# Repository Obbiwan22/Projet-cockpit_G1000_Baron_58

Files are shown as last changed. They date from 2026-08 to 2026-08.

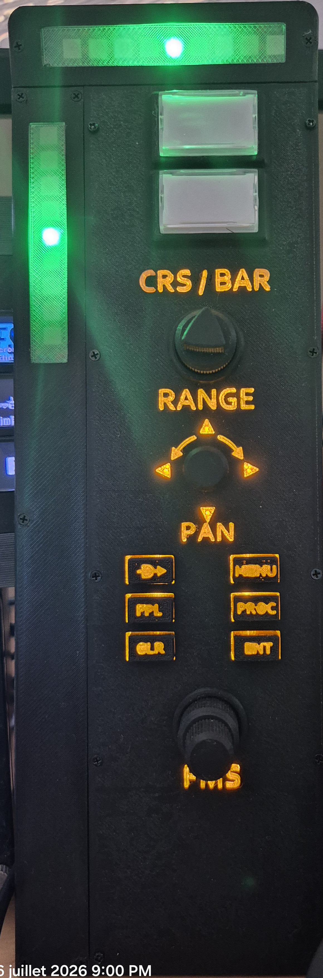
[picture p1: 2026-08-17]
img/G1000.jpg

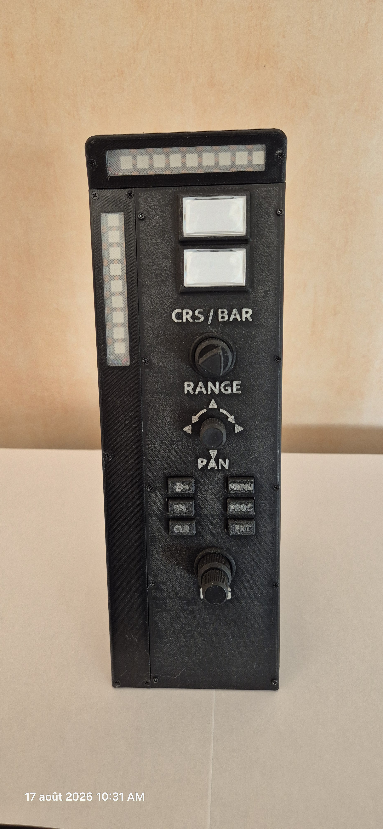
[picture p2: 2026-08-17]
img/Face.jpg

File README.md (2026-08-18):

# G1000 Baron 58 — Cockpit Panel (COMMANDE G1000)

Panneau de commande physique pour le G1000 du Beechcraft Baron 58 sous Microsoft Flight Simulator 2024/2020, piloté par un Arduino Mega 2560 Pro Mini via MobiFlight.





## En bref

Adepte de Flight Simulator, je voulais accéder facilement aux commandes du G1000 sans construire un home cockpit complet. Ce dépôt contient tout ce qu'il faut pour reproduire un panneau de commande physique complet : encodeurs CRS/BARO et FMS, joystick 4 axes, boutons G1000, Master Alarm/Caution avec voyants et alarme sonore, rétro-éclairage variable, et une barre LED qui reproduit l'indicateur de déviation ILS (Localizer/Glideslope).

Le morceau qui a demandé le plus de travail — la barre ILS — a nécessité plusieurs refontes du firmware avant d'obtenir un comportement fiable en vol. Le détail complet de cette investigation est dans le rapport technique (voir plus bas), pour ceux que ça intéresse.

## Démonstration vidéo

- 🎥 [Démonstration 1](https://www.youtube.com/watch?v=X_OnPQQrdoY)
- 🎥 [Démonstration 2](https://www.youtube.com/watch?v=7gS3sEIO30M)

## Ce que contient la carte

| Fonction | Détail |
|---|---|
| Microcontrôleur | Arduino Mega 2560 Pro Mini (CH340G) |
| Encodeurs | CRS/BARO et FMS, EC11EBB24C03 (bagues inner/outer indépendantes) |
| Joystick | 4 axes (Range/Pan), RKJXT1F42001 |
| Boutons | Direct, Menu, Proc, FPL, CLR, Ent |
| Master Alarm / Caution | Boutons illuminés YTS-D001-285 + buzzer NE555 |
| Rétro-éclairage | 2× DM13A chaînés (20 canaux LED) |
| Barre ILS | 2× rubans WS2812B (LOC + GS), 9 LEDs chacun |
| Alimentation | 7.5V DC externe (recommandé) ou USB |

32 broches GPIO du Mega sont mobilisées — sur les 54 disponibles, il en reste tout juste assez pour respirer.

## Structure du dépôt

```
firmware/       Firmware Arduino (.ino/.h/.cpp) — device.json, board.json — Custom Device MobiFlight
schematics/      Schémas EasyEDA (carte CPU + carte COMMANDE G1000)
docs/            Rapport technique complet (FR + EN), BOM, dépannage
tools/           Programme de test matériel autonome + console de contrôle web
Mobiflifht/      Profil Mobiflight mfproj, mfmc
3D-Printing      Fichiers 3MF et STL
img              Photos du projet
```
## Firmware — basé sur MobiFlight

Le firmware `ILS_NeoPixel_mega` est issu du firmware de base **MobiFlight** (version 3.1.0), sur lequel ont été ajoutés/adaptés :
- la gestion de la barre LED ILS (LOC/GS, WS2812B)
- le pilotage des LEDs DM13A (backlighting)
- la gestion des boutons Master Alarm/Caution avec buzzer
- les encodeurs rotatifs CRS/BARO et FMS (double anneau)
- le joystick 4 axes

Le firmware reste compatible avec l'écosystème MobiFlight (upload via MobiFlight Firmware Uploader / PlatformIO, `device.json` conforme au schéma MobiFlight).

## Le morceau intéressant : la logique d'extinction ILS

La vraie difficulté de ce projet n'a jamais été d'afficher la bonne LED — c'est trivial. Le vrai problème a été de l'**éteindre correctement** quand le signal ILS devient invalide. Plusieurs itérations ont été nécessaires avant de comprendre que la cause racine tenait à deux comportements peu documentés de MobiFlight :

- MobiFlight n'envoie une donnée au device **que si la valeur change** — un index de déviation qui reste stable plusieurs secondes en approche stabilisée arrête tout simplement d'être transmis.
- Une config désactivée puis réactivée par précondition **ne rafraîchit pas automatiquement** le matériel tant qu'aucun nouveau changement n'est détecté.

La solution finale retenue : séparer strictement la réception/mémorisation des données (toujours actives, jamais soumises à précondition) de leur affichage (piloté par une gâchette booléenne dédiée, intrinsèquement fiable puisqu'un changement d'état binaire est toujours transmis).

Le détail complet — schémas de câblage, historique des 5 itérations de diagnostic, configuration MobiFlight pas à pas, table de dépannage — est dans le rapport technique.

## Boutons Master Caution / Master Warning — configuration MobiFlight spécifique par appareil

Les boutons **Master Alarm** (SW8, GPIO36 = switch / GPIO37 = LED) et **Master Caution** (SW7, GPIO38 = switch / GPIO39 = LED) sont pilotés matériellement de façon identique pour tous les avions (mêmes GPIO, même buzzer NE555 sur GPIO43). En revanche, **la variable simulateur qui déclenche l'allumage côté MobiFlight change d'un appareil à l'autre** : chaque avion MSFS expose ses propres SimVars / L:Vars pour l'alarme et la caution (nom, type, seuil de déclenchement), donc la config MobiFlight (Config-item / preset) doit être recréée ou adaptée à chaque changement d'appareil piloté par le panneau.

| Appareil | SimVar / L:Var utilisée | Type de config MobiFlight | Remarques |
|---|---|---|---|
| Beechcraft Baron 58 | *(à compléter)* | *(Preset / Custom Code)* | |
| DA62 | *(à compléter)* | | |
| DA40-NG | *(à compléter)* | | |
| DA40 TDI | *(à compléter)* | | |
| TBM 930 | *TBM 930* |MASTER_CAUTION_YELLOW_LED | |
| C208B | *(à compléter)* | | |

**Point d'attention** : contrairement aux SimVars natives disponibles sur certains appareils, plusieurs avions tiers n'exposent l'alarme/caution que via des **L:Vars propres à leur addon**, à retrouver dans la documentation du développeur ou via le débogueur de variables MobiFlight/FSUIPC (WASM) avant de pouvoir créer le Config-item.

> ⚠️ Il n'existe pas de config MobiFlight universelle pour ces deux boutons : à chaque changement d'appareil, vérifier/adapter la variable source dans MobiFlight, sinon les LEDs Master Alarm/Caution restent inertes malgré l'appui physique.

## Boîtier — fabrication en impression 3D

Le boîtier a été entièrement réalisé en impression 3D, sur une imprimante **Creality K2 Pro** (extrudeur direct drive).

**Filament** : PLA pour l'ensemble des pièces structurelles. Le PETG convient également (meilleure tenue mécanique et thermique), mais demande un réglage plus fin.

**Pièces vitrées (PETG transparent)** : certaines pièces nécessitant une transparence optique — pour laisser passer la lumière du rétroéclairage — ont été imprimées en PETG transparent :
- Plaque avant (lettrage)
- Touches fond
- Cales touches
- Glace LOC/GLIDE (fenêtre de la barre LED ILS)

⚠️ **Contrainte d'impression** : l'impression en PETG transparent ne peut se faire qu'à **vitesse très lente**. Une vitesse standard donne un rendu opaque/laiteux qui casse l'effet de transparence recherché pour la diffusion de la lumière.

## Documentation

📄 **[Rapport technique complet](docs/)** (français et anglais) — électronique, firmware, configuration MobiFlight, dépannage

## Statut

✅ Module ILS validé en vol complet (interception → approche stabilisée → toucher des roues), sans extinction intempestive.

🔄 Essais en cours sur d'autres appareils à avionique Garmin (DA62, DA40, famille Cessna 172) pour confirmer la portabilité de la configuration.

## Remerciements

Je ne suis ni électronicien, ni programmeur émérite — juste un passionné de MSFS. Je me suis fait aider dans ce projet pour les parties electroniques et logiciel par Claude (l'IA d'Anthropic), notamment pour déboguer méthodiquement les comportements les plus tordus rencontrés en cours de route. 

## Licence

*Creative Commons Attribution — Pas d'Utilisation Commerciale 4.0 International (CC BY-NC 4.0)*

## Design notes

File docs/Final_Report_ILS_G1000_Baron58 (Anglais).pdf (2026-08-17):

Cockpit G1000 Baron 58 — ILS Module — Final Report

## 3. Firmware

This chapter documents in detail the ILS_NeoPixel_mega firmware, developed as a Custom Device for MobiFlight Community Firmware v11, which drives the entire ILS module (LOC/GS strips and DM13A backlighting) from an Arduino Mega 2560 Pro Mini.

### 3.1 Development Environment

Item | Detail
Target board | Arduino Mega 2560 Pro Mini (CH340G, COM4 port)
IDE / tooling | Visual Studio Code exclusively, with the PlatformIO extension
Terminal | PowerShell (Windows)
Framework | PlatformIO Core CLI, Arduino framework
LED library | FastLED
Base firmware | MobiFlight Community Firmware (Custom Device)

Table 16 — Firmware development environment.

Build command (mandatory before every flash):

$env:VERSION="1.0.1"; pio run ‐e ils_neopixel_mega_ils_neopixel_mega_mega

The VERSION environment variable absolutely must be set on the same line as the pio run command (semicolon separator in PowerShell, not && which isn't valid in this shell), otherwise the generated .hex file isn't named correctly and isn't recognized by MobiFlight when flashing.

### 3.2 Architectural History and Evolution

The firmware went through several significant architectural overhauls before reaching its final, stable version. This history is documented here because it explains certain design choices that might otherwise seem arbitrary.

### 3.2.1 Multi-Class Architecture Attempt (Abandoned)

An initial overhaul attempted to split the monolithic firmware into three independent MobiFlight Custom Devices (ILS_LOC, ILS_GS, LED_Tableau), each with its own .cpp/.h/.device.json files. This approach ran into a series of blocking issues:

- FastLED corruption caused by multiple calls to FastLED.addLeds() (one per class), which FastLED does not support.
- The Community firmware's MFCustomDevice.cpp file did not recognize the new device type names without modifying the firmware core.
- device.json files were silently ignored by MobiFlight in the absence of the "$schema": "./mfdevice.schema.json" field — an omission that produces no visible error, making diagnosis time-consuming.
- Multiple calls to begin() corrupted FastLED's state.
- A board.json file must exist both in Community\ILS_NeoPixel_mega\boards\ AND in the root Boards\ folder — its absence from either location prevents compilation or board recognition.

### 3.2.2 Return to a Monolithic Architecture (Design Adopted)

Faced with these difficulties, the project reverted to a single-class architecture (ILS_NeoPixel_mega), driving both WS2812B strips and the DM13A backlighting from a single object, with one message identifier (messageID)

per function: 0 for LOC, 1 for GS, 2 for backlighting. This simpler architecture proved considerably more robust and forms the basis for all the later developments described in this chapter.

### 3.2.3 The LOC/GS Extinguishing Problem: A Multi-Stage Investigation

The most significant difficulty encountered on this project concerned the LOC/GS LED extinguishing logic when the ILS signal becomes invalid (out of range, tail-on to the runway, before signal capture). This problem required several rounds of diagnosis, each one revealing a deeper cause than the last. The table below summarizes this investigation, in chronological order.

# | Hypothesis / Design Tested | Result | Root Cause

1 | Firmware timeout alone (3000 ms), no
| GS handling | GS never turned off | The update() code only checked
| | | the timeout for LOC — GS timeout
| | | handling was completely absent.

2

Added 2 MobiFlight outputs “ILS OFF LOC/GS” based on NAV HAS GLIDE SLOPE, in parallel with the main outputs based on ILS_ACTIVE

Random extinguishing during approach, LEDs sometimes
stayed on when out of range

Race condition: two MobiFlight configs wrote to the same channel (same messageID) from two
different, unsynchronized
SimVars, with no execution-order arbitration.

3

Dedicated firmware gate ILS_ACTIVE (dedicated messageID), immediate extinguishing on receipt

Freezing reappeared: LEDs
stayed on or off without
updating

MobiFlight only sends data to the device when the computed final value changes (“send on change”) — if the LOC/GS index stays stable for several seconds (common during a stabilized approach), no more data is sent at all.

4

MobiFlight precondition (NAV HAS GLIDE SLOPE = 1/0) on the LOC/GS outputs themselves, with dedicated “OFF” outputs on the same variable

LEDs stayed off after a turn, despite a correct final value shown in the interface

Documented MobiFlight behavior: a config that goes from disabled (precondition false) back to enabled does not automatically push a new value to the hardware unless a new change is detected.

5

Final design: LOC/GS always active and continuously cached on the firmware side (no precondition), ILS_ACTIVE gate dedicated solely to display, immediate redisplay from cache on every toggle

Validated on a complete flight,
no spurious extinguishing | —

Table 17 — History of successive diagnoses of the LOC/GS extinguishing logic.

### 3.3 Design final retenu

The final architecture rests on a simple principle: strictly separate receiving/caching data from displaying it.

- The LOC (messageID 0) and GS (messageID 1) messages are always transmitted by MobiFlight, with no precondition whatsoever, and are systematically cached by the firmware in two variables (_lastLocIndex, _lastGsIndex), whether or not they are being displayed at that moment.
- A dedicated ILS_ACTIVE message (messageID 3, MSG_ILS_ACTIVE) serves exclusively as a display “trigger”: at 0, both strips are turned off immediately; at 1, they are redisplayed immediately from the cached values, without waiting for a new LOC/GS message that might be delayed if the value hasn't changed in the meantime.
- The timeout mechanism, which had turned out to be the source of several extinguishing false positives (see Table 17, row 3), was removed entirely from the update() function. Extinguishing is now handled exclusively by this explicit gate.

This design removes the dependency on MobiFlight's “send on change” behavior for the extinguishing logic: a boolean that toggles (0→1 or 1→0) is always a value change, and is therefore always reliably transmied — unlike a LOC/GS index rounded to 9 discrete levels, which can stay identical for several seconds in a row during a stabilized approach.

### 3.4 Header File Description (ILS_NeoPixel_mega.h)

The header file defines the hardware constants (pins, number of LEDs, brightness), the trigger message identifier, and the class declaration.

#define ILS_MAX_LEDS 9

#define ILS_BRIGHTNESS 80

#define ILS_PIN_LOC | 7 | // GPIO6 → D6 LOC DIN

#define ILS_PIN_GS | 6 | // GPIO7 → D7 GS DIN

#define DM13A_EN | 5 | // GPIO5 → D5 PWM

#define DM13A_LAT 49 | // D49 | libre

#define DM13A_SS | 53 | // GPIO53 → D53 SS

#define MSG_ILS_ACTIVE 3 | // gate d’affichage

The class exposes the standard methods of a MobiFlight Custom Device (begin, attach, detach, set, update) plus three additional member variables specific to the final design: _ilsActive (gate state), _lastLocIndex and _lastGsIndex (cache of the last indexes received, initialized to -1 to represent “no data / out of range”).

### 3.5 Detailed Source File Description (ILS_NeoPixel_mega.cpp)

### 3.5.1 Color Palette

A static array of 9 RGB colors maps each LED index to a color, symmetric around the center (index 4, green): bright red at the extremes (maximum deviation), passing through dark orange, orange, and yellow.

### 3.5.2 The set() Function — Receiving MobiFlight Messages

This is the heart of the firmware, called by the MobiFlight connector on every message received over the serial link. The switch on messageID distinguishes five cases:

messageID | Function | Behavior
MSG_ILS_ACTIVE (3) | Display gate | Updates _ilsActive. If 0: both strips are turned off immediately. If 1: immediate redisplay from the cache (_lastLocIndex / _lastGsIndex) via showIndex().
-1 / -2 | Connector stop / Power Saving | Both strips turned off immediately (standard MobiFlight behavior).
0 | LOC bar | Updates _lastLocIndex and its associated timestamp in every case; calls showIndex() only if _ilsActive is true.
1 | GS bar | Same logic as LOC, on _lastGsIndex.
2 | DM13A backlighting | Directly applies the brightness value (0-255) via setBL(), unrelated to the ILS_ACTIVE gate.

Table 18 — Behavior of the set() function by messageID (final version).

### 3.5.3 The showIndex() Function — Rendering on a Strip

A utility function shared by both strips: if the index received is outside the [0-8] range (which can happen transiently during large deviations, e.g. during a turn), the entire strip is turned off. Otherwise, only the LED matching the index is lit, with its palette color; all others are turned off.

void ILS_NeoPixel_mega::showIndex(CRGB* strip, int idx) {
if (idx < 0 || idx > 8) {
fill_solid(strip, ILS_MAX_LEDS, CRGB::Black);
} else {
for (int i = 0; i < ILS_MAX_LEDS; i++) {
strip[i] = (i == idx) ? PALETTE[i] : CRGB::Black; }
}
FastLED.show();
}

### 3.5.4 The update() Function — Called Every Loop

In the final version, this function is deliberately emptied of all extinguishing logic. It only keeps an initialization check, since extinguishing is now entirely the responsibility of the ILS_ACTIVE gate handled in set(). The _lastUpdateLOC / _lastUpdateGS variables are kept for potential future diagnostics but no longer trigger any action.

### 3.5.5 DM13A Functions (Backlighting)

Three functions manage the backlighting via the two chained DM13A chips: dm13a_byte() (sends one byte over bit-banged SPI), dm13a() (sends a full 32-bit mask to both chained chips, with the EN#/SS/LAT sequence), and setBL() (converts a 0-255 brightness value into a PWM signal on the EN# pin, knowing that a high value on EN# means off and a low value means full brightness — hence the 255-val inversion).

## 4. MobiFlight Configuration

This chapter documents the MobiFlight Community Firmware configuration needed to use the ILS_NeoPixel_mega firmware: Custom Device declaration (device.json), output configuration (SimVars, transforms, preconditions), and the internal ILS_ACTIVE variable.

### 4.1 Custom Device — device.json

The device.json file declares the device type to MobiFlight and the list of Message Types available in the interface (dropdown in the Display tab of each output). It must include the "$schema" field to be recognized — its absence causes a silent failure (no error shown, the device simply doesn't appear).

{
"$schema": "./mfdevice.schema.json",
"Info": {
"Label": "ILS NeoPixel Mega", "Type": "ILS_NeoPixel_mega", "Author": "francois.colas22",
"Version": "1.0.3"
},
"Config": { "Pins": ["DIN LOC", "DIN GS"], "isI2C": false }, "MessageTypes": [
{ "id": 0, "label": "LOC Index (0‐8)" },
{ "id": 1, "label": "GS Index (0‐8)" },
{ "id": 2, "label": "Luminosite DM13A (0‐255)" }, { "id": 3, "label": "ILS Active (0/1)" }
]
}

### 4.2 Output Configuration

The table below summarizes the final, flight-validated configuration of the four MobiFlight outputs required for
the ILS module.
Output | Sim Variable | Transform (Modify) | Message Type | Precondition
ILS LOC | NAV CDI:1 | Floor(($+127)/254*8+0.5) | LOC Index (0-8) | none
ILS Glide | NAV GLIDE SLOPE:1 | Floor((($*-1)+1)/2*8+0.5) | GS Index (0-8) | none
ILS ACTIVE OUT | NAV HAS GLIDE SLOPE:1 | $ (raw) | ILS Active (0/1) | none
Backlighting LED Panel | LIGHT POTENTIOMETER:3 | Floor($/100*255) | Luminosite DM13A (0-
255) none

Table 19 — Final MobiFlight output configuration.

Points to watch, identified during the project:

- Transform functions are case-sensitive: Floor() with a capital F works; floor() in lowercase causes a silent parsing error in the MobiFlight logs (“Transform error… An error occurred on parsing your value formula”), with no visible sign anywhere else in the interface — only the application log reveals it.
- None of the LOC, Glide, or ACTIVE OUT outputs should carry a precondition in the final design: it's the firmware gate (ILS_ACTIVE) that handles extinguishing, not MobiFlight.
- LIGHT POTENTIOMETER:3 (not :21 or :85, two values tested by mistake during the project) is the SimVar that actually controls the panel lighting on the Baron 58.

### 4.3 Internal ILS_ACTIVE Variable

The ILS_ACTIVE gate is not directly an MSFS SimVar: it's an internal MobiFlight Variable, fed by NAV HAS GLIDE SLOPE:1. A MobiFlight Variable cannot be written from the Display tab of a standard output (“Output Device”): it requires the “Input Action” Display option, with action type “MobiFlight - Variable”.

Tab | Setting
Sim Variable | Source: Microsoft Flight Simulator, SimVar NAV HAS GLIDE SLOPE:1, Unit Bool
Modify | No transform (raw value)
Display | Choose = Input Action, trigger On Change, Action Type = MobiFlight - Variable, Type Number, Name ILS_ACTIVE, Value $
Precondition | none

Table 20 — Configuration feeding the ILS_ACTIVE variable.

This variable is then used as a precondition (type “Config item”, directly referencing the “ILS_ACTIVE” config itself) for other specific needs on the MobiFlight side; the firmware, meanwhile, receives the signal state via the “ILS ACTIVE OUT” output from Table 19, which reads NAV HAS GLIDE SLOPE:1 directly and sends it to the physical device — the internal variable and the physical output share the same source but remain two separate configs.

### 4.4 Summary of SimVars Used

MSFS SimVar | Role in the Project | Range
NAV CDI:1 | Localizer deviation (LOC) | -127 to +127
NAV GLIDE SLOPE:1 | Glideslope error (GS) | -1.0 to +1.0
NAV HAS GLIDE SLOPE:1 | Indicates whether the tuned station has a glideslope | 0 or 1 (boolean)
LIGHT POTENTIOMETER:3 | Baron 58 panel light rheostat | 0 to 100

Table 21 — MSFS 2024 SimVars used by the ILS module.

Documented point to note: NAV HAS GLIDE SLOPE:1 indicates that the tuned frequency has a glideslope (station capability), not that the aircraft is currently receiving a valid, usable signal. After testing, no simple, reliable SimVar explicitly indicating “a valid ILS signal is being received right now” was identified in MSFS 2024 (NAV SIGNAL:1 and NAV CDI:1 were also tested for this specific purpose without success). The system accepts this residual limitation: in edge cases (frequency tuned but aircraft outside the useful geometry), a slight transient display mismatch remains possible, with no effect on normal operation, which has been thoroughly validated in flight.

### 4.5 Buzzer and Master Alarm / Master Caution Buttons

⚠ Warning — Unlike the ILS module (whose every config was built and verified step by step in MobiFlight, screenshots included), this part had not yet been detailed in this report. The content below comes from the project's summary notes and has not been re-verified config by config in the MobiFlight interface like the rest of this chapter — to be confirmed if the wiring or configuration has changed since.

The buzzer (NE555, §2.2.3) and the LEDs of the Master Alarm/Master Caution buttons (§2.4.6) are driven from MobiFlight via the GPIOs already identified in the Electronics chapter, triggered by the G1000's SimConnect events:

Output | GPIO | Trigger
Buzzer NE555 (BUZ1) | GPIO43 | MASTER_WARNING_ACTIVE SimConnect event (continuous sound) or MASTER_CAUTION_ACTIVE (brief sound)
LED bouton Master Alarm (SW8) | GPIO37 | Follows MASTER_WARNING_ACTIVE state
LED bouton Master Caution (SW7) | GPIO39 | Follows MASTER_CAUTION_ACTIVE state

Table 22 — Buzzer and Master Alarm/Caution LED triggers (source: project summary notes, to be re-verified in MobiFlight).

The two buttons themselves (NC/NO contact, GPIO36 for SW8 and GPIO38 for SW7, cf. §2.4.6) are set up on the MobiFlight side as a Button-type Input Config, to allow the Master Alarm/Caution to be acknowledged (reset) from the physical panel.

ℹ Info — To document this section with the same level of rigor as the ILS module (screenshots of the Sim Variable / Modify / Display / Precondition tabs), each relevant config would need to be reopened in MobiFlight — feel free to share them with me if you'd like me to fill in the table above with the exact transform details and the SimConnect event names used.

## 5. Troubleshooting — Lessons Learned

This chapter gathers, as a quick-reference table, all the symptoms encountered during the project, their cause, and the solution adopted. It is meant to speed up any future diagnosis on this module or a similar one.

Symptom | Cause | Solution
GS stays on indefinitely when out of range | Complete absence of timeout handling for GS in update() (initial bug) | GS timeout added, later replaced by the ILS_ACTIVE gate in the final design
Random extinguishing during approach | Race condition between two MobiFlight outputs writing to the same channel from different, unsynchronized sources | Unify all preconditions on a single source, then drop the precondition in favor of the firmware gate
LEDs freeze after a few seconds of stability | MobiFlight only sends a value to the device if it has changed; a rounded index can stay identical for several seconds | Dedicated boolean gate (always reliably transmitted since a 0/1 change is always detected) + firmware cache

LEDs off despite a correct “Final Value” shown in MobiFlight

Re-enabling a config disabled by a precondition doesn't automatically push a new value to the device

Remove all preconditions on the LOC/GS outputs; keep a
precondition only on the gate itself, which is an always-transmitted boolean
“Transform error” in the logs, LEDs stuck at a fixed value | Lowercase floor() not recognized by MobiFlight's NCalc expression engine (case-sensitive) | Use Floor() with a capital F
device.json silently ignored by MobiFlight | Missing "$schema" field in the file | Toujours inclure "$schema": "./mfdevice.schema.json"
Incorrect .hex filename after compilation | VERSION variable not defined on the same line as pio run | Always use $env:VERSION="1.0.1"; pio run -e … (semicolon, not &&, in PowerShell)
“Choose variable” dropdown empty for a MobiFlight Variable-type precondition | This menu only lists variables already read by another output, not ones that are only written | Create an output that reads the variable and use it as a “Config item”-type precondition

LED lights up in an inconsistent color outside the useful range (turn, large deviation)

The raw value exceeds the range expected by the transform, producing an index outside 0-8

Accepted behavior: showIndex() automatically turns off if the index falls outside [0,8], which is the desired behavior in these transient cases

Master Caution LED (SW7) shifts to green when SW8 (Master Alarm) is activated at the same time | Likely coupling via a shared ground return between R4 (red, SW8) and R5 (red, SW7), not isolated from R10's return (green, SW7) — confirmed by a software test: forcing GPIO37 without physically pressing SW8 reproduces the color shift | To be fixed in the next PCB revision: ensure R4, R5, and R10 each independently reach a continuous ground plane, with no shared return path between them. A multimeter measurement (clean ground vs. R5/R10 junction) should be taken once the PCB is reopened
Master Caution LED (SW7) lit pure red instead of yellow | R- and G- on SW7 were wired in parallel on a single resistor (R5) on the common-anode side — the red LED (lower Vf) hogged the current, leaving the green channel nearly off | Resolved: added R10 (220Ω) dedicated to the green channel, in an independent series path from R5 (red channel) — each color now has its own current-limiting resistor, correct yellow blend obtained (SW7 alone, excluding

Symptom | Cause | Solution
| | the interaction with SW8 — see next row)

Table 23 — Troubleshooting reference.

## 6. Conclusion

The ILS module (Localizer/Glideslope LED bar) of the G1000 Baron 58 cockpit is now functional and validated under real flight conditions: interception, capture, extended stabilized approach, and touchdown all proceed without spurious extinguishing or erratic behavior. The physical wiring is considered final.

The main lesson from this project goes beyond the strict scope of electronics or code: the central difficulty was never in the business logic itself (displaying a deviation index), but in the subtleties of MobiFlight's behavior as a middle layer — in particular its practice of only sending data on value change, and the incomplete refresh of configs when a precondition is re-enabled. These two behaviors, not obviously documented, led to several rounds of diagnosis before the root cause was clearly identified each time.

The final solution adopted — a strict separation between receiving/caching data (always active, never subject to a precondition) and displaying it (driven by a dedicated boolean gate, inherently reliable since a binary state change is always transmitted) — forms a robust, reusable architecture for any future module of this kind on the same platform.

Testing is currently continuing on other aircraft (Diamond DA62, DA40, Cessna 172 family) to confirm this configuration's portability to other Garmin avionics in MSFS 2024.

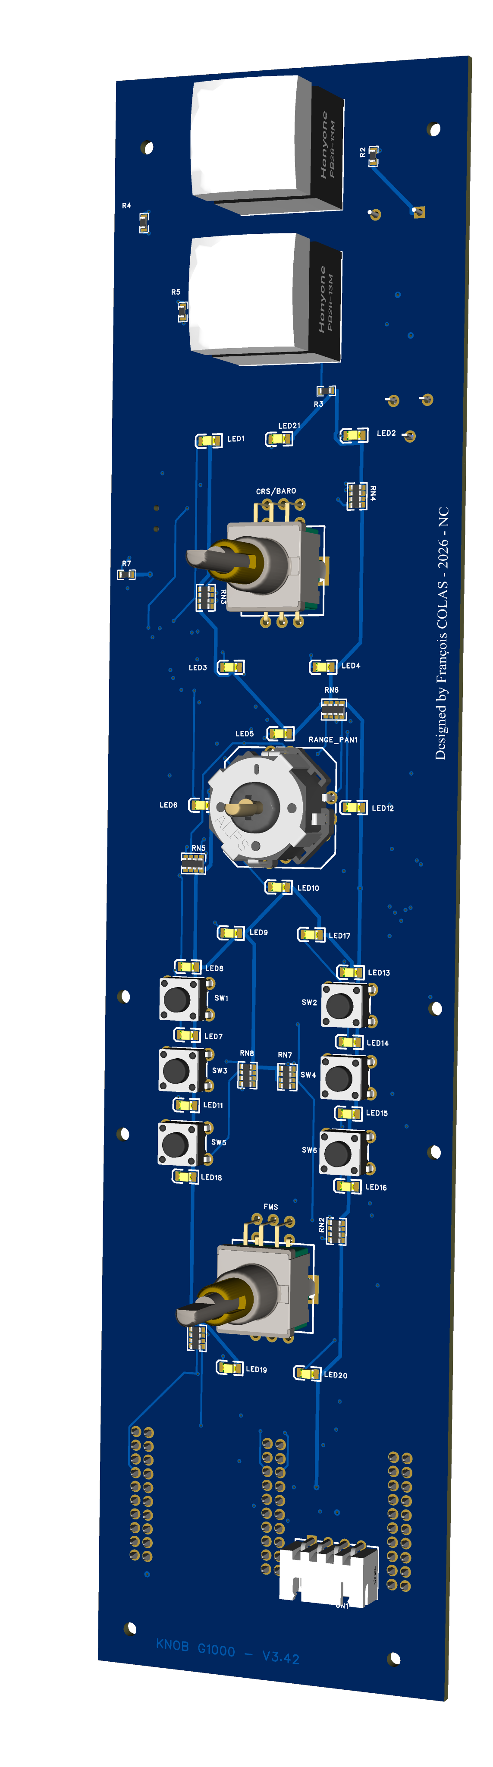
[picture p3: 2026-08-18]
img/Platine Bouton sound .png

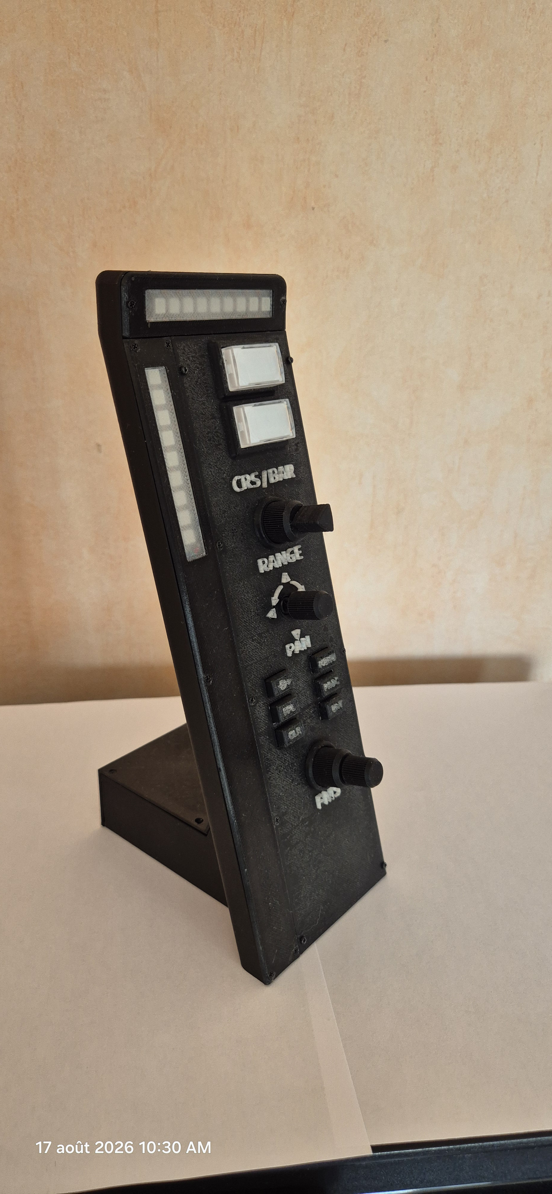
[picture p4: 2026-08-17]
img/Gauche.jpg

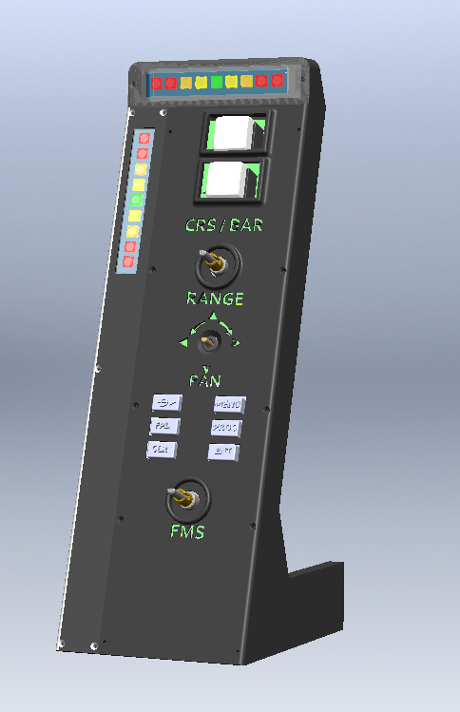
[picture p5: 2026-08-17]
Boitier.jpg

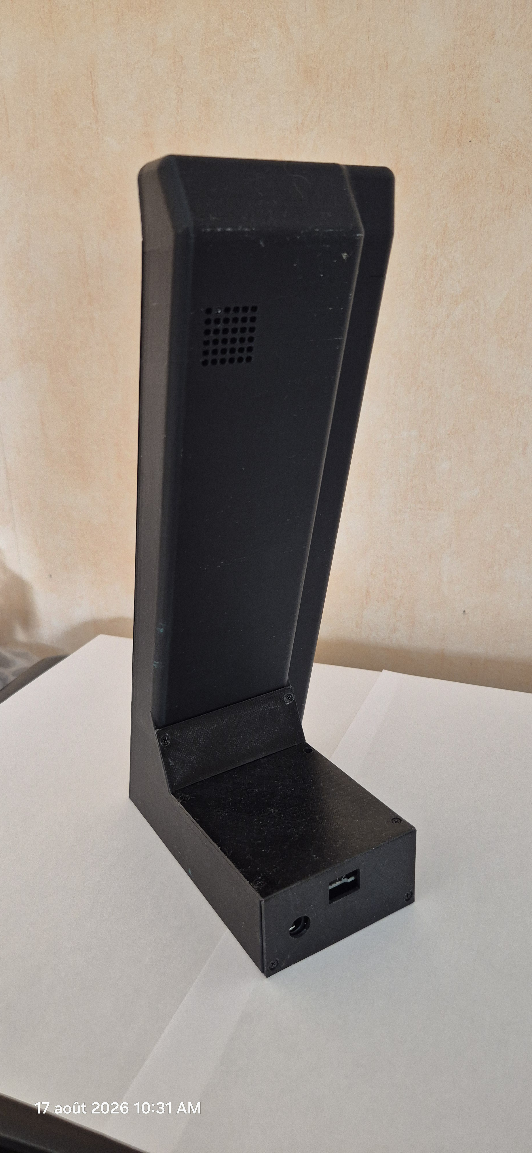
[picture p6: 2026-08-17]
img/Arriere.jpg

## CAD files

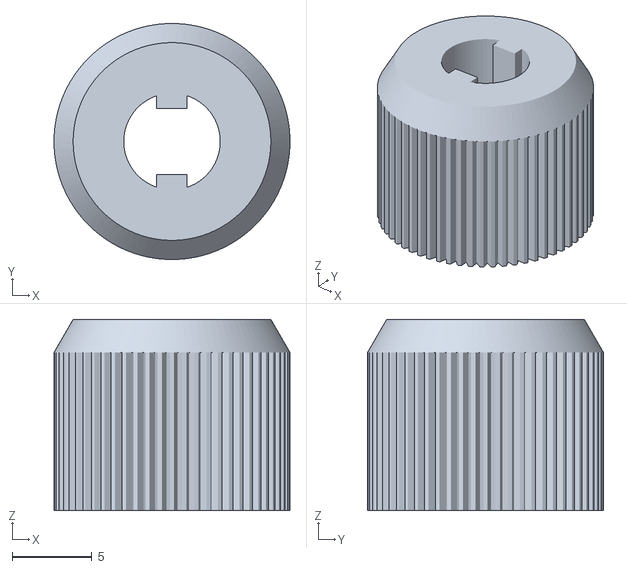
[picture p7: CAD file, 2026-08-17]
3D-Printing/knob_outer.stl
14.8 x 14.8 x 12.0

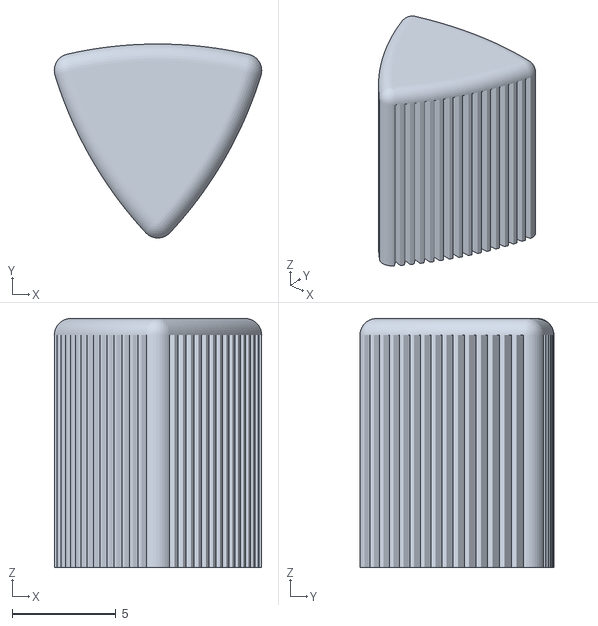
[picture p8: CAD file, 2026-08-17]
3D-Printing/knob_inner_crs.stl
10.0 x 9.35 x 12.0

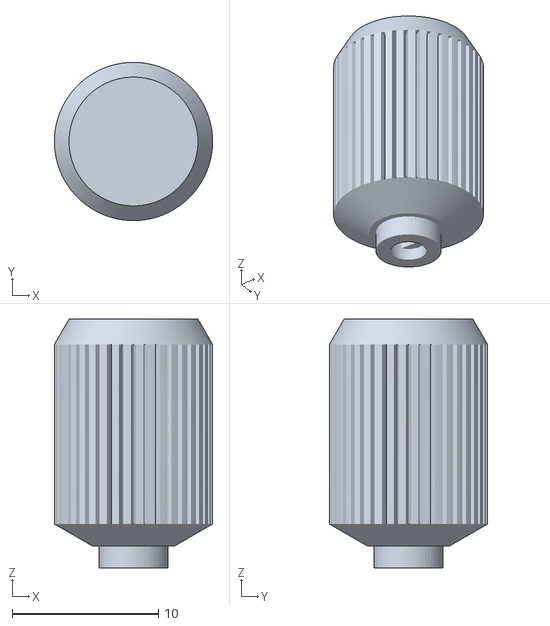
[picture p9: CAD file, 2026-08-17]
3D-Printing/knob_4dir.stl
10.8 x 10.8 x 17.0

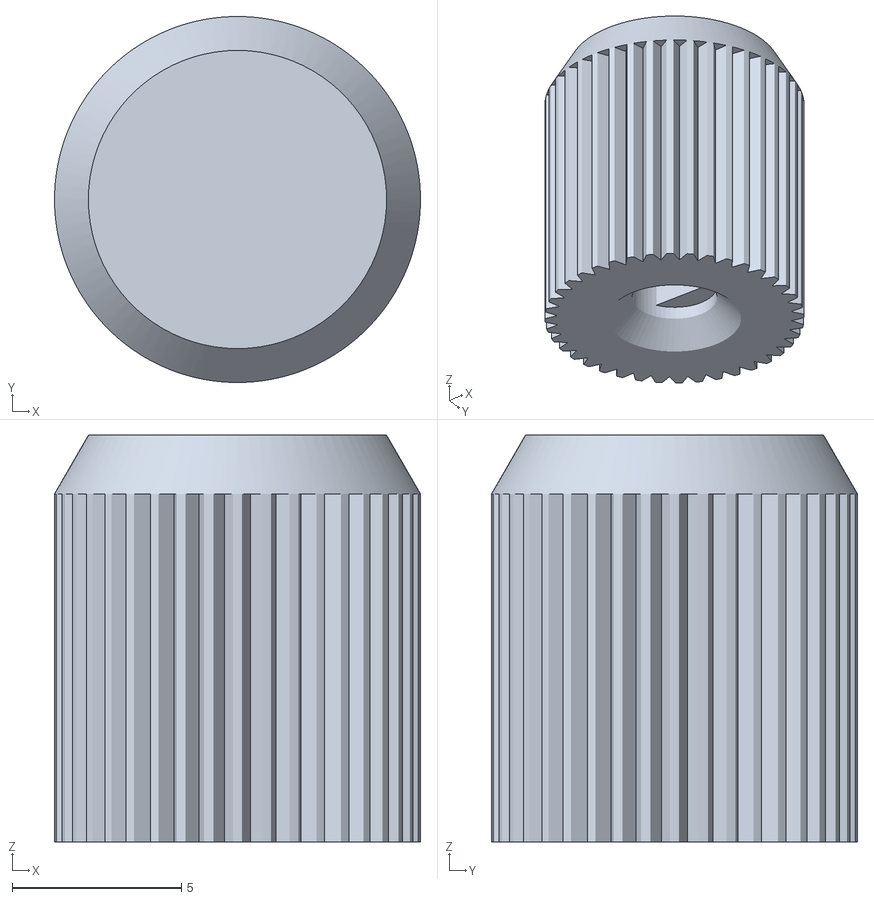
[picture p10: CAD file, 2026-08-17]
3D-Printing/knob_innter.stl
10.8 x 10.8 x 12.0

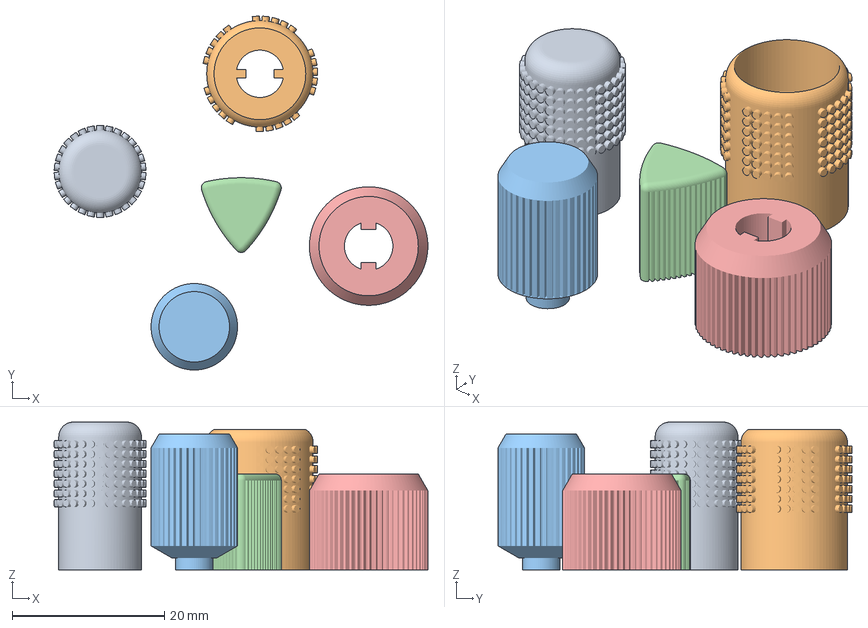
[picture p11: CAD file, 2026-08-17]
3D-Printing/Bouton_Knob.3mf
49.0 x 46.4 x 19.4 mm
EC11_InnerKnob
EC11_OuterKnob.STL
knob_4dir.stl
knob_inner_crs.stl
knob_outer.stl

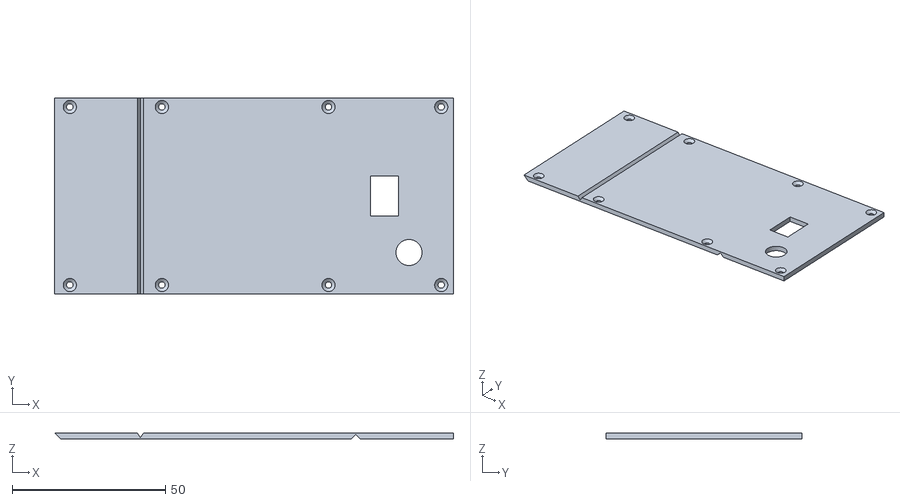
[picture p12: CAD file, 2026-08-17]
3D-Printing/Capot-arriere.STL
130.0 x 64.0 x 2.00

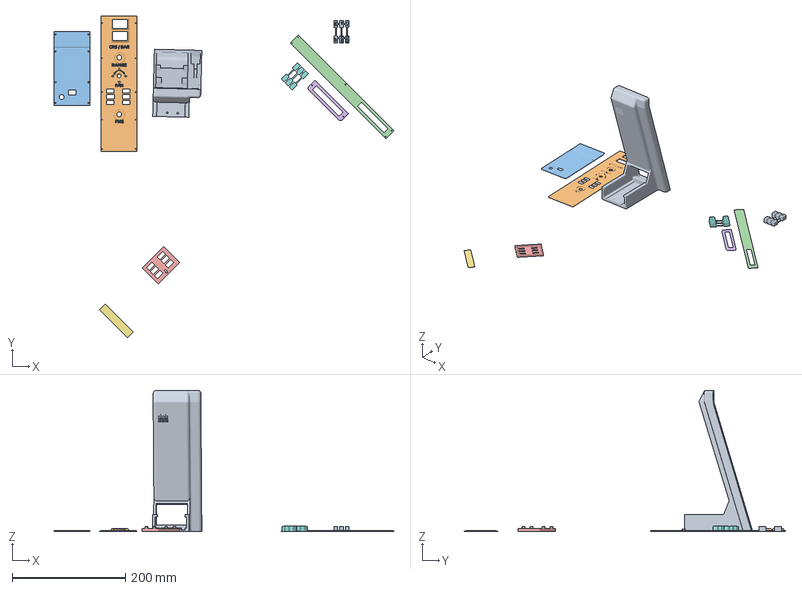
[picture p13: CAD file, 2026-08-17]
3D-Printing/Boitier.3mf
600.8 x 568.4 x 249.3 mm
Knob V3.42.STL
plaque avant V3.42.STL
Capot-arriere.STL
Plaque_GLIDE.STL
Cale touche 3.2.STL
Plaque_LOC.STL
Glasse_LOC_GLIDE.STL
Touches_fond V3.2.STL
Touches_coque 3.2.STL

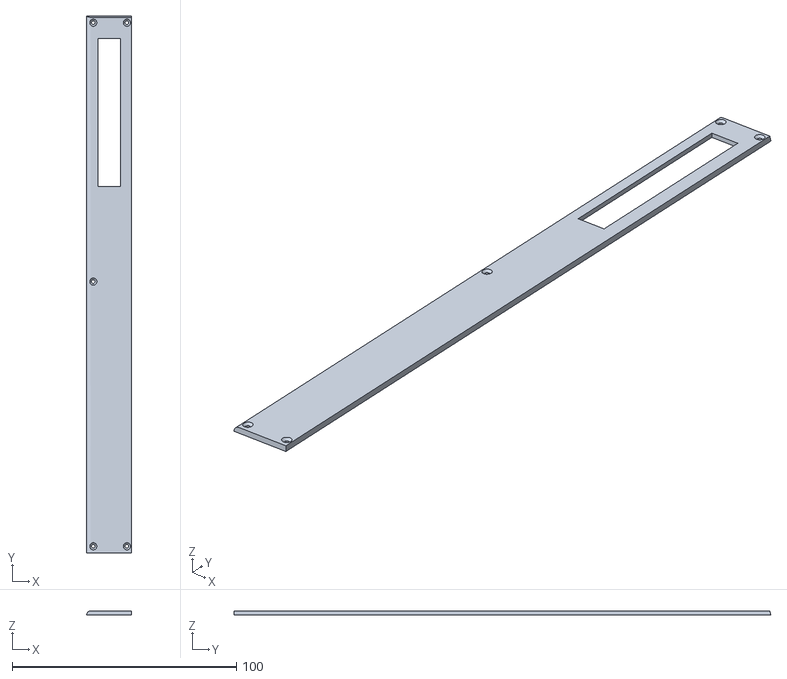
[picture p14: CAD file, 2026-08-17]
3D-Printing/Plaque_GLIDE.STL
20.0 x 239.4 x 2.00

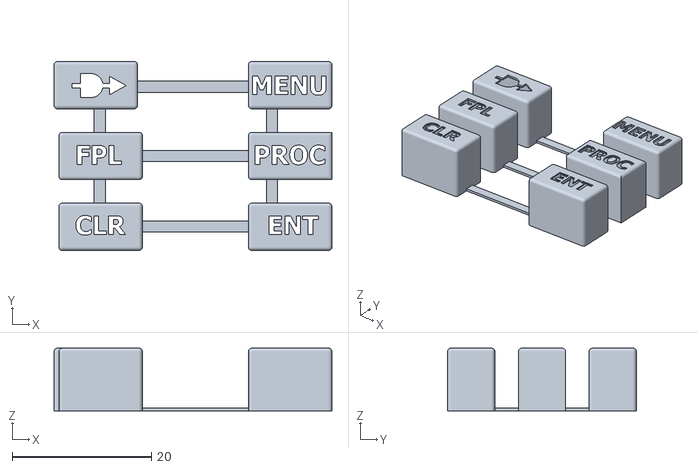
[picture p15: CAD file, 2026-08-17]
3D-Printing/Touches_coque 3.2.STL
39.9 x 27.1 x 9.00

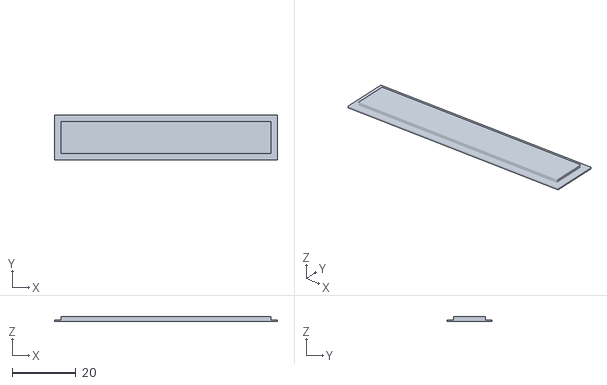
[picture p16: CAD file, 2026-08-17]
3D-Printing/Glasse_LOC_GLIDE.STL
70.0 x 14.0 x 1.50

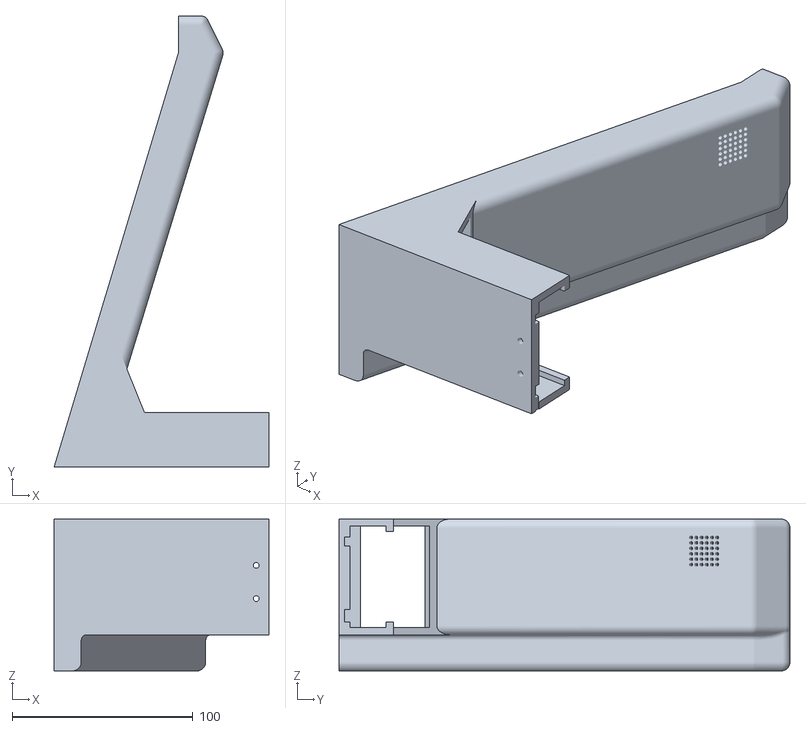
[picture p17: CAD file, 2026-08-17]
3D-Printing/Knob V3.42.STL
118.7 x 249.3 x 84.0

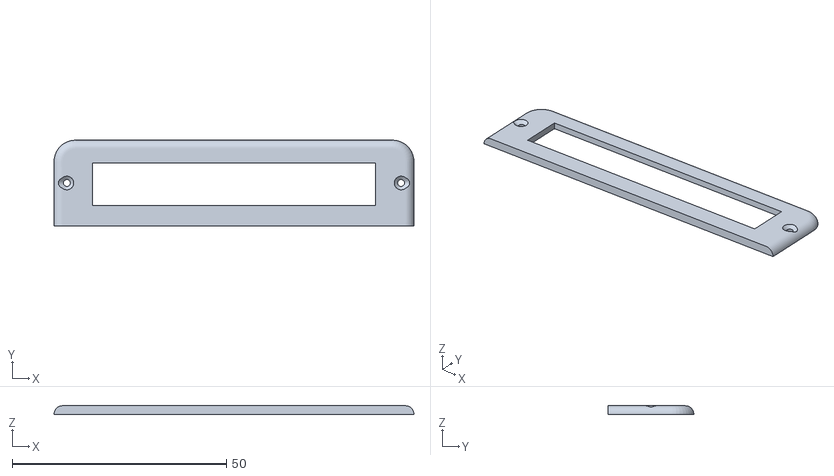
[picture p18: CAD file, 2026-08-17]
3D-Printing/Plaque_LOC.STL
84.0 x 20.0 x 2.00

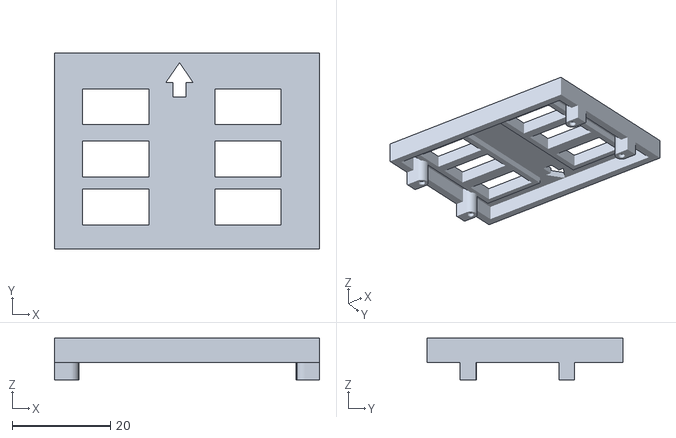
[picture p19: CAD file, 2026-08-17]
3D-Printing/Cale touche 3.2.STL
54.0 x 40.0 x 8.50

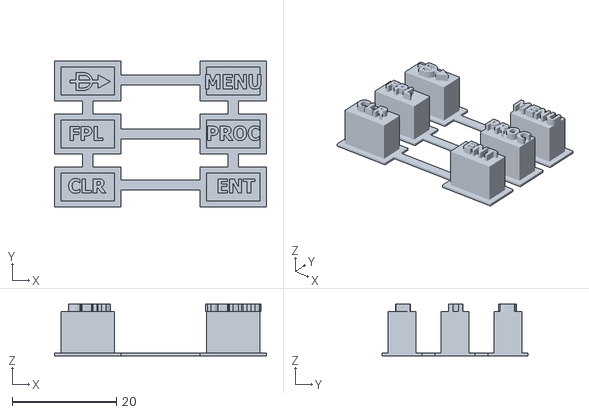
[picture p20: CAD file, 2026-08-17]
3D-Printing/Touches_fond V3.2.STL
40.7 x 28.0 x 9.90

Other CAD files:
3D-Printing/plaque avant V3.42.STL
3D-Printing/plaque avant lettre V3.2.STL

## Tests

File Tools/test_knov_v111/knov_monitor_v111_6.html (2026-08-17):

KNOV V3.3

Moniteur GPIO — G1000 Baron 58

Mega 2560 Pro Mini · v1.0.11 · WebSerial

DÉCO Connecter Suivant →

Cliquer "Connecter" — Chrome/Edge requis (WebSerial) Effacer

💡 WS2812B LOC ÉTEINT

← GaucheCENTRE[4]Droite →

D7/GPIO7LOC DIN — CN3

—

💡 WS2812B GS ÉTEINT

↑ HautSUR PLAN[4]Bas ↓

D6/GPIO6GS DIN — CN3

—

🔆 DM13A SPI 0/32

SS D53/G53Chip select CN5

LAT D49Latch enable (libre)

SCK D52/G52SPI hardware

MOSI D51/G51SPI hardware

+5VVDD +5V master + slave ✓

EN# D5/G5GPIO5 → master + slave reliés ✓

0%

🎛️ Encodeurs EC11

FMS — A1:D16/G16 A2:D17/G17 B1:D20/G20 B2:D21/G21 SW:D8/G8

0

0

attente...

SW

A1 D16/G16

—

B1 D20/G20

—

CRS — A1:D24/G24 A2:D25/G25 B1:D22/G22 B2:D23/G23 SW:D11/G11

0

0

attente...

SW

A1 D24/G24

—

B1 D22/G22

—

🔘 Boutons G1000 0

FPL0D32/G31

PROC0D35/G32

CLR0D31/G30

MENU0D34/G35

ENT0D30/G34

DIRECT0D33/G33

🕹️ Joystick · Son · Master · VCC

RKJXT1 — UP:D26 L:D27 D:D28 R:D29 PUSH:D15 ROT:D18/D19

↑ D26

← D27

PSH

D29 →

↓ D28

D15/G15PUSH

D18/G18ROT ←

D19/G19ROT →

Son NE555 — D43/GPIO43

🔊

Silence

0 bips

1 bip 3 bips

Master Caution/Alarm

⚠️

Caution

LED D39

BTN D38/G38

🔔

Alarm

LED D37

BTN D36/G36

CAU ON CAU OFF ALM ON ALM OFF

VCC

—

En attente

🔆 Rétro-éclairage DM13A — EN# D5/GPIO5 · master + slave · SimVar MSFS MANUEL

💡

EN# D5 → master + slave simultané · SimVar MSFS → BL:OE=0..255

Luminosité OE D5 — master + slave0%

Presets: OFF 25% 50% 75% MAX 🔄 Fade

32 canaux (clic=toggle)

Tous ON Tous OFF Pairs Impairs

🎯 Commandes manuelles ILS — LOC D7 · GS D6

Sweep

↺ Reset

━━ LOC 4

←G D→

Dév: SUR L'AXEidx 4

┃┃ GS 4

↑H B↓

Dév: SUR LE PLANidx 4

📋 Log série0

▶ Démo Envoyer 'n' 🔊 Bip ⬇ Export

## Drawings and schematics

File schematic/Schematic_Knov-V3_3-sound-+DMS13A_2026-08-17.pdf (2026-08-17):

Inner | Outder
Inner | Outder

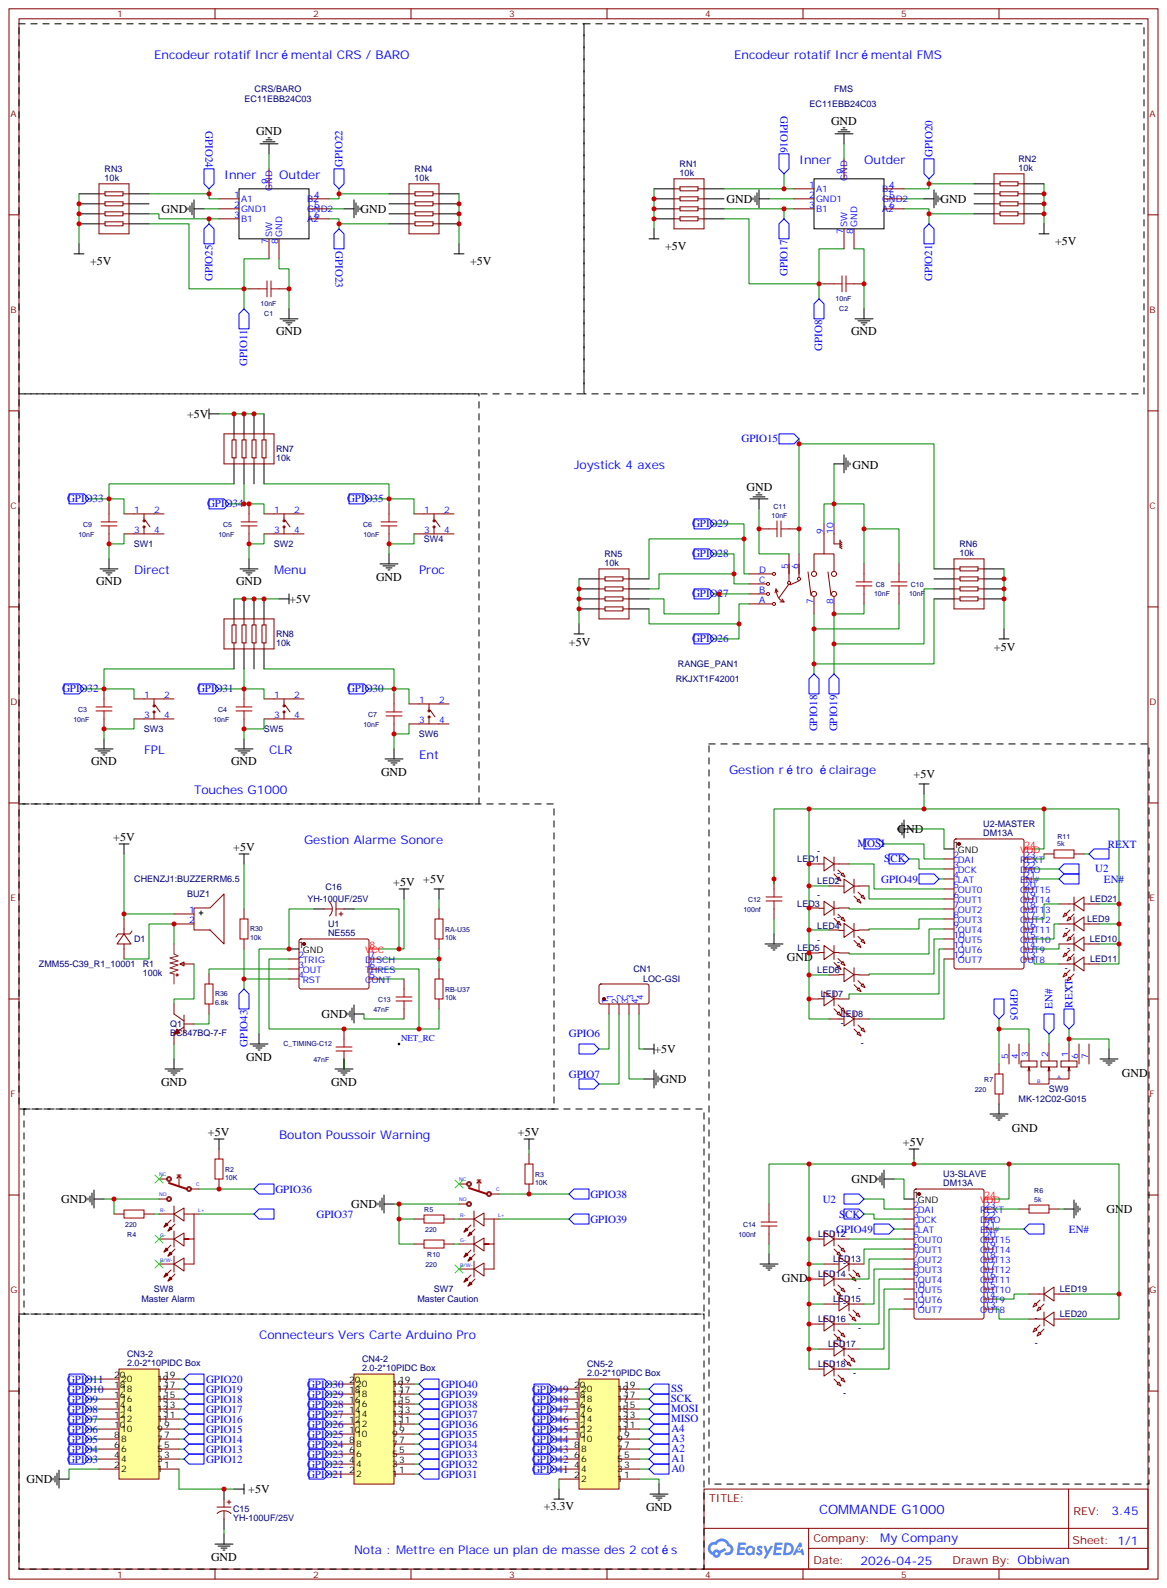
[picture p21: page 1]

Connecteurs Vers Carte Arduino Pro

Nota : Mettre en Place un plan de masse des 2 cot s

# Arduino Mega Pro GND 745V 765V 773V3 783V3 79AREF 80RST 81

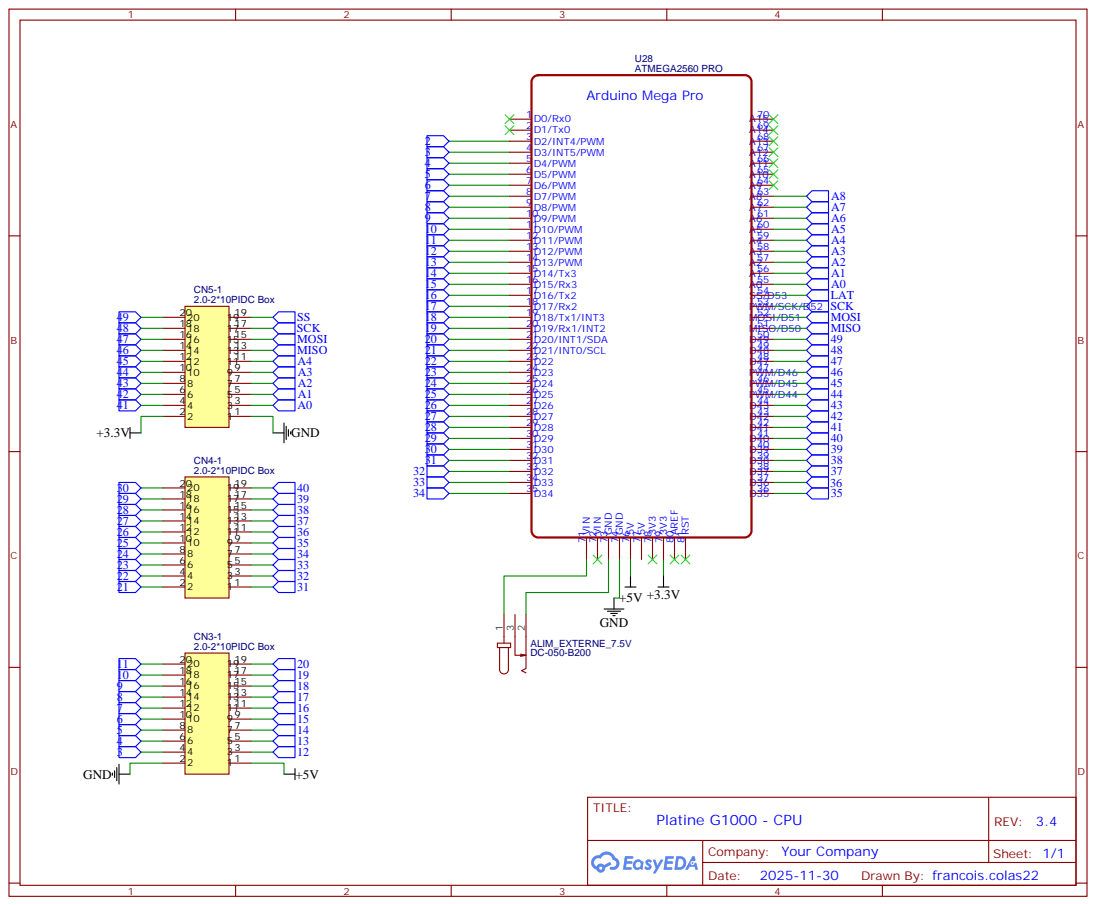
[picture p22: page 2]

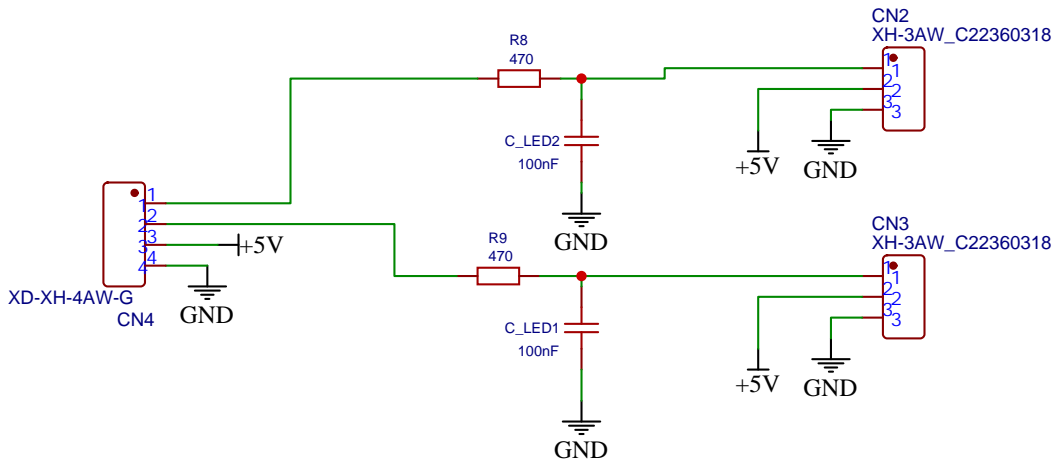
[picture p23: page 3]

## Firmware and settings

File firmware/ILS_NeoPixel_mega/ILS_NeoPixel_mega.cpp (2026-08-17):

// ============================================================
//  ILS_NeoPixel_mega.cpp
//
//  Barre LED ILS pour Microsoft Flight Simulator 2024
//  Custom Device MobiFlight v11 – Community Firmware
//
//  Description :
//    Pilote deux rubans WS2812B de 9 LEDs chacun via FastLED :
//      - Barre LOC (Localizer)   : déviation horizontale
//      - Barre GS  (Glideslope) : déviation verticale
//
//    Chaque barre affiche une seule LED allumée dont la couleur
//    indique la déviation :
//      LED 0/8 : rouge vif    (déviation maximale)
//      LED 1/7 : orange foncé
//      LED 2/6 : orange
//      LED 3/5 : jaune
//      LED 4   : vert vif     (sur l'axe / sur le plan)
//
//    Extinction pilotée par ILS_ACTIVE (messageID MSG_ILS_ACTIVE) :
//    LOC/GS sont toujours reçus et mémorisés (aucune précondition
//    côté MobiFlight sur ces deux-là), seul l'AFFICHAGE dépend du
//    gate ILS_ACTIVE, réaffiché immédiatement à chaque bascule pour
//    éviter toute dépendance à un nouveau message LOC/GS après coup.
//    ILS_TIMEOUT_MS reste un pur filet de sécurité (perte de liaison
//    série), il ne doit quasiment jamais se déclencher.
//
//  Matériel :
//    - Arduino Mega 2560 Pro Mini
//    - Ruban WS2812B LOC : pin D6
//    - Ruban WS2812B GS  : pin D7
//    - Alimentation 5V USB (luminosité limitée à 80/255)
//
//  SimVars MSFS 2024 :
//    - LOC : NAV CDI:1              (plage -127 à +127)
//      Transform : Floor(($ + 127) / 254 * 8 + 0.5)
//    - GS  : NAV GLIDESLOPE ERROR:1 (plage -1.0 à +1.0, inversée)
//      Transform : Floor((($ * -1) + 1) / 2 * 8 + 0.5)
//    - Précondition : NAV HAS GLIDE SLOPE:1 (bool)
//
//  Auteur  : francois.colas22
//  Projet  : Cockpit G1000 – Beechcraft Baron 58
//  Licence : MIT
//  Version : 1.0.2
// ============================================================
 
#include "ILS_NeoPixel_mega.h"
#include "allocateMem.h"
#include "commandmessenger.h"
 
// ── Tableaux LEDs et flag statiques globaux ──────────────────
static CRGB ledsLOC[ILS_MAX_LEDS];
static CRGB ledsGS[ILS_MAX_LEDS];
static bool _fastledReady = false;  // FastLED.addLeds ne s'exécute qu'une seule fois
 
// ── Palette de couleurs par index LED ────────────────────────
// Index 0 = déviation max gauche/haut (rouge)
// Index 4 = centré sur l'axe          (vert)
// Index 8 = déviation max droite/bas  (rouge)
static const CRGB PALETTE[ILS_MAX_LEDS] = {
    CRGB(255,   0,   0),  // 0 – rouge vif      (déviation maximale)
    CRGB(255,  60,   0),  // 1 – orange foncé
    CRGB(255, 120,   0),  // 2 – orange
    CRGB(220, 200,   0),  // 3 – jaune
    CRGB(  0, 255,   0),  // 4 – vert vif        (centré sur l'axe ILS)
    CRGB(220, 200,   0),  // 5 – jaune
    CRGB(255, 120,   0),  // 6 – orange
    CRGB(255,  60,   0),  // 7 – orange foncé
    CRGB(255,   0,   0),  // 8 – rouge vif      (déviation maximale)
};
 
// ── DM13A SPI bitbang ────────────────────────────────────────
void ILS_NeoPixel_mega::dm13a_byte(uint8_t val)
{
    for (int b = 7; b >= 0; b--) {
        digitalWrite(51, (val >> b) & 1);  // MOSI D51
        digitalWrite(52, HIGH);             // SCK  D52
        delayMicroseconds(1);
        digitalWrite(52, LOW);
        delayMicroseconds(1);
    }
}

void ILS_NeoPixel_mega::dm13a(uint32_t mask)
{
    uint16_t hi = (uint16_t)(mask >> 16);
    uint16_t lo = (uint16_t)(mask & 0xFFFF);
    digitalWrite(DM13A_EN, HIGH);
    delayMicroseconds(2);
    digitalWrite(DM13A_SS, LOW);
    dm13a_byte((hi >> 8) & 0xFF);
    dm13a_byte( hi       & 0xFF);
    dm13a_byte((lo >> 8) & 0xFF);
    dm13a_byte( lo       & 0xFF);
    digitalWrite(DM13A_SS, HIGH);
    digitalWrite(DM13A_LAT, HIGH);
    delayMicroseconds(5);
    digitalWrite(DM13A_LAT, LOW);
    digitalWrite(DM13A_EN, LOW);
}

void ILS_NeoPixel_mega::setBL(uint8_t val)
{
    // val=255 → OE LOW  → max luminosité
    // val=0   → OE HIGH → éteint
    analogWrite(DM13A_EN, 255 - val);
}

// ─────────────────────────────────────────────────────────────
// CONSTRUCTEUR
// Reçoit les deux pins DIN des rubans WS2812B.
// Note : FastLED nécessite des pins connus à la compilation
// (templates C++), donc ILS_PIN_LOC et ILS_PIN_GS sont des
// constantes définies dans ILS_NeoPixel_mega.h (#define).
// ─────────────────────────────────────────────────────────────
ILS_NeoPixel_mega::ILS_NeoPixel_mega(uint8_t Pin1, uint8_t Pin2)
{
    _pin1          = Pin1;   // DIN LOC (D6)
    _pin2          = Pin2;   // DIN GS  (D7)
    _initialised   = false;
    _lastUpdateLOC = 0;
    _lastUpdateGS  = 0;
    _ilsActive     = false;
    _lastLocIndex  = -1;   // -1 = pas encore de donnée, hors plage → blanc
    _lastGsIndex   = -1;
}
 
// ─────────────────────────────────────────────────────────────
// BEGIN – Initialise FastLED et éteint toutes les LEDs
// Appelé une seule fois lors du premier attach().
// ─────────────────────────────────────────────────────────────
void ILS_NeoPixel_mega::begin()
{
    if (!_fastledReady) {
        // FastLED.addLeds appelé UNE SEULE FOIS pour toutes les instances
        FastLED.addLeds<WS2812B, ILS_PIN_LOC, GRB>(ledsLOC, ILS_MAX_LEDS);
        FastLED.addLeds<WS2812B, ILS_PIN_GS,  GRB>(ledsGS,  ILS_MAX_LEDS);
        FastLED.setBrightness(ILS_BRIGHTNESS);

        // TEST VISUEL : toutes LEDs blanches 2s au démarrage
        fill_solid(ledsLOC, ILS_MAX_LEDS, CRGB::White);
        fill_solid(ledsGS,  ILS_MAX_LEDS, CRGB::White);
        FastLED.show();
        delay(2000);
        fill_solid(ledsLOC, ILS_MAX_LEDS, CRGB::Black);
        fill_solid(ledsGS,  ILS_MAX_LEDS, CRGB::Black);
        FastLED.show();

        // DM13A init
        pinMode(51,        OUTPUT); digitalWrite(51,        LOW);
        pinMode(52,        OUTPUT); digitalWrite(52,        LOW);
        pinMode(DM13A_SS,  OUTPUT); digitalWrite(DM13A_SS,  HIGH);
        pinMode(DM13A_LAT, OUTPUT); digitalWrite(DM13A_LAT, LOW);
        pinMode(DM13A_EN,  OUTPUT); digitalWrite(DM13A_EN,  LOW);
        dm13a(0xFFFFFFFF);

        _fastledReady = true;
    }
 
    // Initialiser les timestamps à maintenant
    _lastUpdateLOC = millis();
    _lastUpdateGS  = millis();

    _initialised = true;
}
 
// ─────────────────────────────────────────────────────────────
// ATTACH – Appelé par MobiFlight lors du chargement de la config
// Pin3 est le 3ème paramètre de config (non utilisé ici).
// init contient la chaîne de configuration EEPROM.
// ─────────────────────────────────────────────────────────────
void ILS_NeoPixel_mega::attach(uint16_t Pin3, char *init)
{
    _pin3 = Pin3;
    // Initialiser FastLED au premier attach seulement
    if (!_initialised) begin();
}
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

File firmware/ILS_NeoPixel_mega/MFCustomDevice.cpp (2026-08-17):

#include "MFCustomDevice.h"
#include "commandmessenger.h"
#include "allocateMem.h"
#include "MFEEPROM.h"
#if defined(HAS_CONFIG_IN_FLASH)
#include "MFCustomDevicesConfig.h"
#else
const char CustomDeviceConfig[] PROGMEM = {};
#endif

extern MFEEPROM MFeeprom;

/* **********************************************************************************
    The custom device pins, type and configuration is stored in the EEPROM
    While loading the config the adresses in the EEPROM are transferred to the constructor
    Within the constructor you have to copy the EEPROM content to a buffer
    and evaluate him. The buffer is used for all 3 types (pins, type configuration),
    so do it step by step.
    The max size of the buffer is defined here. It must be the size of the
    expected max length of these strings.

    E.g. 6 pins are required, each pin could have two characters (two digits),
    each pins are delimited by "|" and the string is NULL terminated.
    -> (6 * 2) + 5 + 1 = 18 bytes is the maximum.
    The custom type is "ILS_NeoPixel_mega", which means 14 characters plus NULL = 15
    The configuration is "myConfig", which means 8 characters plus NULL = 9
    The maximum characters to be expected is 18, so MEMLEN_STRING_BUFFER has to be at least 18
********************************************************************************** */
#define MEMLEN_STRING_BUFFER 40

// reads a string from EEPROM or Flash at given address which is '.' terminated and saves it to the buffer
bool MFCustomDevice::getStringFromMem(uint16_t addrMem, char *buffer, bool configFromFlash)
{
    char     temp     = 0;
    uint8_t  counter  = 0;
    uint16_t length   = MFeeprom.get_length();
    do {
        if (configFromFlash) {
            temp = pgm_read_byte_near(CustomDeviceConfig + addrMem++);
            if (addrMem > sizeof(CustomDeviceConfig))
                return false;
        } else {
            temp = MFeeprom.read_byte(addrMem++);
            if (addrMem > length)
                return false;
        }
        buffer[counter++] = temp;              // save character and locate next buffer position
        if (counter >= MEMLEN_STRING_BUFFER) { // nameBuffer will be exceeded
            return false;                      // abort copying to buffer
        }
    } while (temp != '.'); // reads until limiter '.' and locates the next free buffer position
    buffer[counter - 1] = 0x00; // replace '.' by NULL, terminates the string
    return true;
}

MFCustomDevice::MFCustomDevice()
{
    _initialized = false;
}

/* **********************************************************************************
    Within the connector pins, a device name and a config string can be defined
    These informations are stored in the EEPROM or Flash like for the other devices.
    While reading the config from the EEPROM or Flash this function is called.
    It is the first function which will be called for the custom device.
    If it fits into the memory buffer, the constructor for the customer device
    will be called
********************************************************************************** */

void MFCustomDevice::attach(uint16_t adrPin, uint16_t adrType, uint16_t adrConfig, bool configFromFlash)
{
    if (adrPin == 0) return;

    /* **********************************************************************************
        Do something which is required to setup your custom device
    ********************************************************************************** */

    char   *params, *p = NULL;
    char    parameter[MEMLEN_STRING_BUFFER];
    uint8_t _pin1, _pin2, _pin3;

    /* **********************************************************************************
        Read the Type from the EEPROM or Flash, copy it into a buffer and evaluate it
        The string get's NOT stored as this would need a lot of RAM, instead a variable
        is used to store the type
    ********************************************************************************** */
    getStringFromMem(adrType, parameter, configFromFlash);
    if (strcmp(parameter, "ILS_NeoPixel_mega") == 0)
        _customType = MY_CUSTOM_DEVICE_1;
    if (strcmp(parameter, "ILS_NeoPixel_mega2") == 0)
        _customType = MY_CUSTOM_DEVICE_2;

    if (_customType == MY_CUSTOM_DEVICE_1) {
        /* **********************************************************************************
            Check if the device fits into the device buffer
        ********************************************************************************** */
        if (!FitInMemory(sizeof(ILS_NeoPixel_mega))) {
            // Error Message to Connector
            cmdMessenger.sendCmd(kStatus, F("Custom Device does not fit in Memory"));
            return;
        }
        /* **********************************************************************************************
            Read the pins from the EEPROM or Flash, copy them into a buffer
            If you have set '"isI2C": true' in the device.json file, the first value is the I2C address
        ********************************************************************************************** */
        getStringFromMem(adrPin, parameter, configFromFlash);
        /* **********************************************************************************************
            Split the pins up into single pins. As the number of pins could be different between
            multiple devices, it is done here.
        ********************************************************************************************** */
        params = strtok_r(parameter, "|", &p);
        _pin1  = atoi(params);
        params = strtok_r(NULL, "|", &p);
        _pin2  = atoi(params);
        params = strtok_r(NULL, "|", &p);
        _pin3  = atoi(params);

        /* **********************************************************************************
            Read the configuration from the EEPROM or Flash, copy it into a buffer.
        ********************************************************************************** */
        getStringFromMem(adrConfig, parameter, configFromFlash);
        /* **********************************************************************************
            Split the config up into single parameter. As the number of parameters could be
            different between multiple devices, it is done here.
            This is just an example how to process the init string. Do NOT use
            "," or ";" as delimiter for multiple parameters but e.g. "|"
            For most customer devices it is not required.
            In this case just delete the following
        ********************************************************************************** */
        uint16_t Parameter1;
        char    *Parameter2;
        params     = strtok_r(parameter, "|", &p);
        Parameter1 = atoi(params);
        params     = strtok_r(NULL, "|", &p);
        Parameter2 = params;
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

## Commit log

2026-08-17 Add Imprim 3D update README
    [Boitier.3mf, Cale touche 3.2.STL, Capot-arriere.STL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]
2026-08-17 Add Stl
    [Bouton_Knob.3mf, knob_4dir.stl, knob_inner_crs.stl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]
2026-08-18 Rename Folder update README
    [Boitier.3mf, Bouton_Knob.3mf, Cale touche 3.2.STL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]
